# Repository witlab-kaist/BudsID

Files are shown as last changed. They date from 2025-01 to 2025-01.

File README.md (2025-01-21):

# BudsID
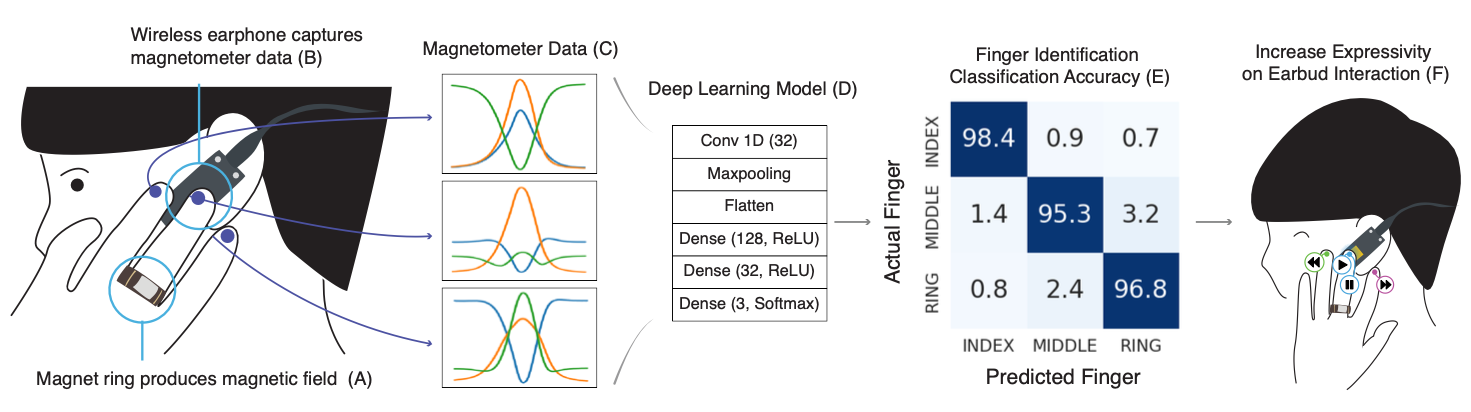
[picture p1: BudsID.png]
BudsID
    

BudsID: Mobile-Ready and Expressive Finger Identification Input for Earbuds.     
Jiwan Kim, Mingyu Han, and Ian Oakley    
CHI '25: Proceedings of the 2025 CHI conference on Human Factors in Computing systems.    
[DOI]() | [Video]()    

## About
This open-source provides software, hardware, and classifier for BudsID.

## Software
```
Software/    
├── Arduino_LSM9DS1.zip    
├── Arduino_TensorFlowLite.zip     
├── nanoBuds_v4/    
│   ├── model.h     
│   ├── nanoBuds_v4.ino     
│   ├── src/    
│   │   ├── CapacitiveSensor/    
├── nanoBudsBLE_v5/    
│   ├── index.html    
│   ├── nanoBudsBLE_v5.js    
│   └── libraries/    
└── readMe.txt    
```
- Arduino_LSM9DS1.zip: This archive contains external libraries required for achieving a higher magnetometer sampling rate.
- Arduino_TensorFlowLite.zip: Libraries to enable tinyML on microcontollers
- nanoBuds_v4/:
    - nanoBuds_v4.ino: This Arduino (.ino) file consists of the code responsible for BLE communication and TensorFlow Lite for Microcontrollers.
- model.h: trained model.
- CapacitiveSensor/: This directory contains an external library related to capacitive sensing.
- nanoBudsBLE_v5/:
    - index.html: This webpage provides a user interface for viewing magnetometer, accelerometer, gyroscope data, and capacitive touch inputs via a BLE connection.
- readMe.txt: This is the project's README file, providing additional details and instructions.
- Data preprocessing and classifier code will be shared with github repository with publication of this work.

## Hardware
#### Components:    
Parts - Sensor unit   
> https://store-usa.arduino.cc/products/arduino-nano-33-ble-sense   
> Resistors and 7mm x 7mm x 0.7 plated PCB (for electrode):   
> 	- https://playground.arduino.cc/Main/CapacitiveSensor/   

Parts - Battery unit   
> Voltage booster: https://www.adafruit.com/product/4654   
> Battery: 3.7 li-ion (36 x 17 x 6.5mm)   
> Charger: see included kicad project, based on https://www.adafruit.com/product/2124   

USB micro Cable: any with diameter ~4mm.   

#### Assembly Instructions:   
```
1. Create a sensor or battery module for left or right ear using an appopriate base and top part. 
(sensorBaseLeft.stl plus sensorTop.stl are for a left sensor earbud, powerBaseRight.stl plus powerTop.stl are for a right power earbud).   
2. The battery unit clicks shut.    
3. The sensor unit should be secured with M1 bolts (10mm) and nuts.    
4. Screw the appropriate earLoop (left or right) to the loopToBaseConnector with an M2 bolt (8-12mm) and nut. The nut is in the connector.    
5. Slide the connector onto the sensor or battery base (it will be very stiff).    
6. Push the outerEarStrut into the hole on the earLoop and fit a rubber earbud over it.    
```

## Classifier    
BudsID_classifier.ipynb file illustrate preprocessing and classifier design code.   

## Contact    
Jiwan Kim: [kjwan4435@gmail.com](mailto:kjwan4435@gmail.com)

## Reference

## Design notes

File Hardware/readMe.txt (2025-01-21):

Assembly Instructions:

All models are in the Models folder

Create a sensor or battery module for left or right ear using an appopriate base and top part. For example:
sensorBaseLeft.stl plus sensorTop.stl are for a left sensor earbud
powerBaseRight.stl plus powerTop.stl are for a right power earbud

The battery unit clicks shut. The sensor unit should be secured with M1 bolts (10mm) and nuts. 

Screw the appropriate earLoop (left or right) to the loopToBaseConnector with an M2 bolt (8-12mm) and nut. The nut is in the connector. 

Slide the connector onto the sensor or battery base (it will be very stiff). 

Push the outerEarStrut into the hole on the earLoop and fit a rubber earbud over it. 

Parts - Sensor unit
https://store-usa.arduino.cc/products/arduino-nano-33-ble-sense
Resistors and 7mm x 7mm x 0.7 plated PCB (for electrode):
	- https://playground.arduino.cc/Main/CapacitiveSensor/

Parts - Battery unit
Voltage booster: https://www.adafruit.com/product/4654
Battery: 3.7 li-ion (36 x 17 x 6.5mm)
Charger: see included kicad project, based on https://www.adafruit.com/product/2124
USB micro Cable: any with diameter ~4mm.

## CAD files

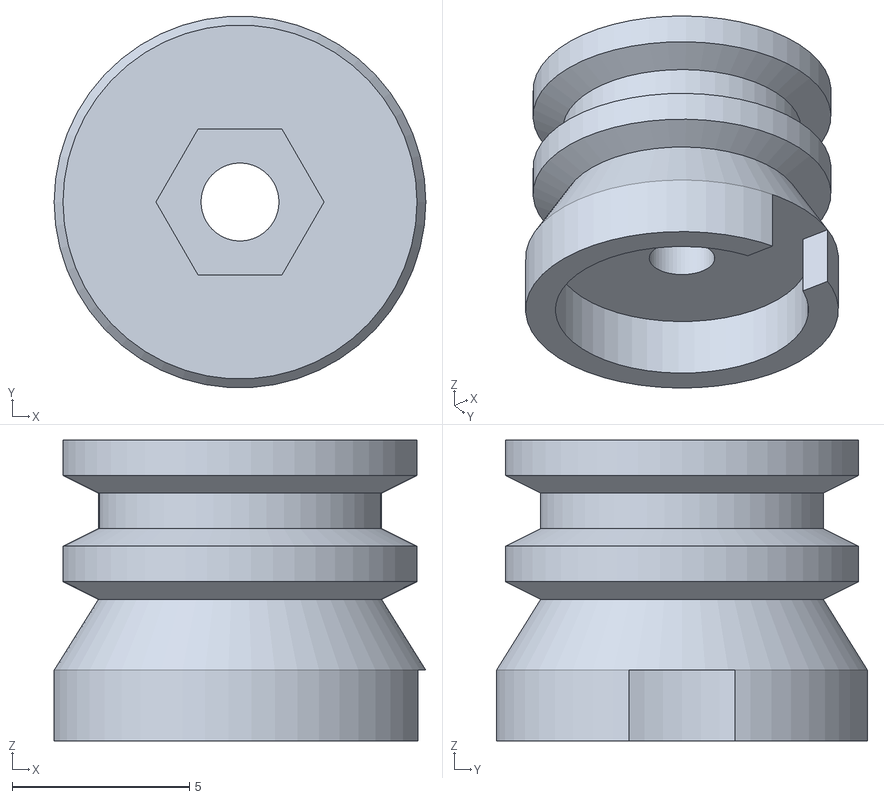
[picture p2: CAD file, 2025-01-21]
Hardware/Models/loopToBaseConnector.stl
10.5 x 10.5 x 8.50

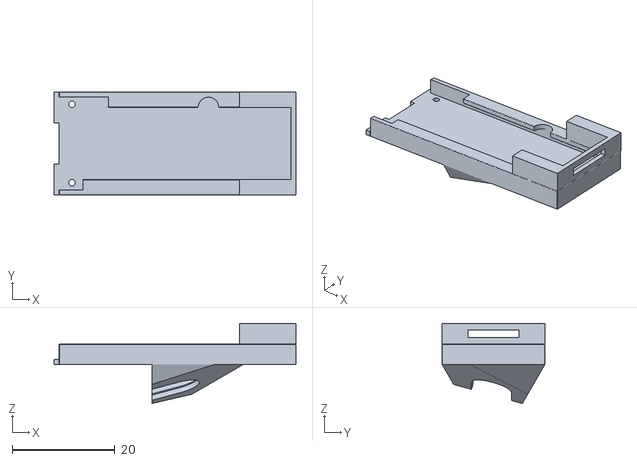
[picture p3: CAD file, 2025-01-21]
Hardware/Models/sensorBaseLeft.stl
47.0 x 20.0 x 15.5

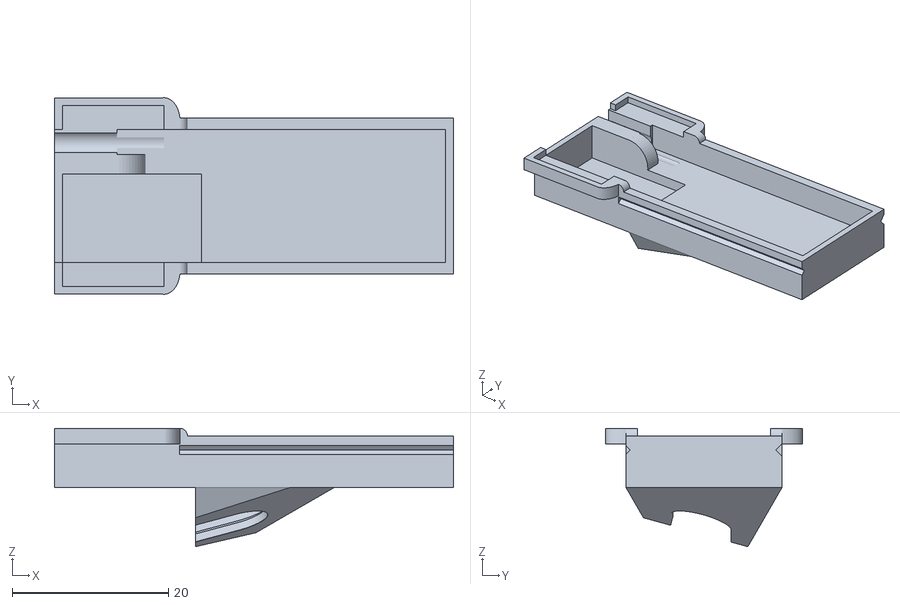
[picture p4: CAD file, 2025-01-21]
Hardware/Models/powerBaseLeft.stl
51.0 x 25.1 x 15.1

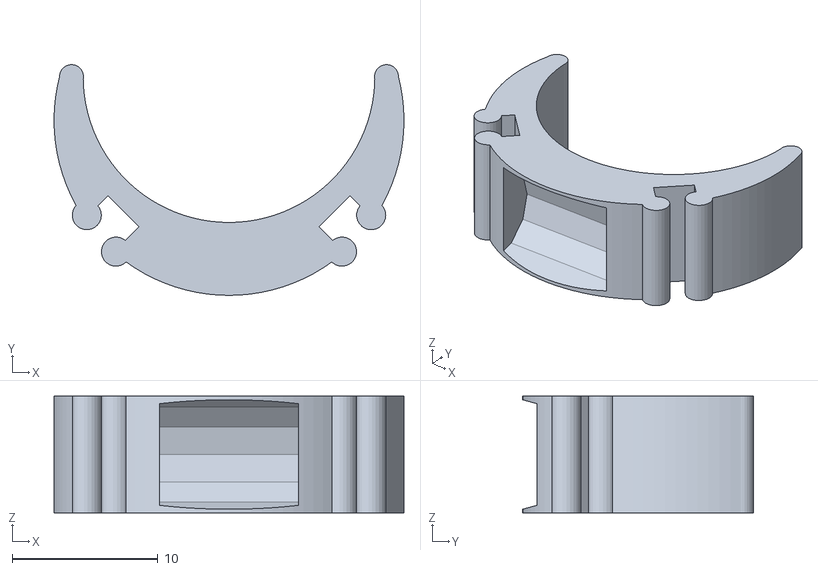
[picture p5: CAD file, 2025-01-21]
Hardware/Models/magnetRing.stl
24.0 x 15.8 x 8.00

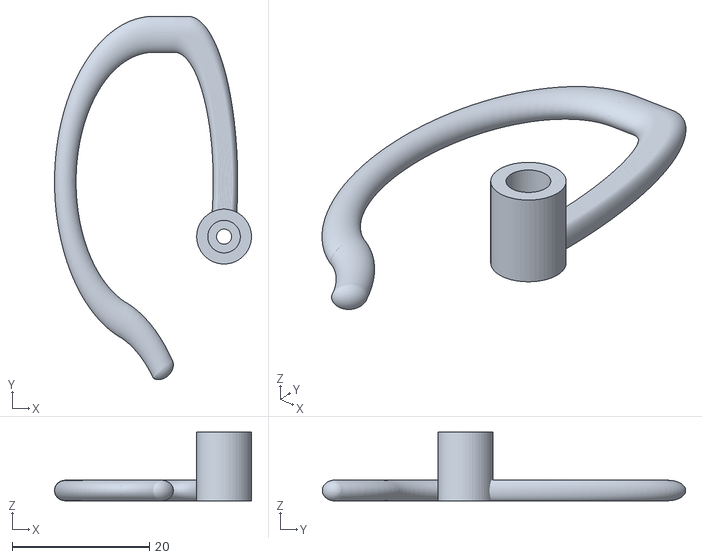
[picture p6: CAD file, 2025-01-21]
Hardware/Models/earLoopLeft.stl
28.7 x 53.0 x 10.0

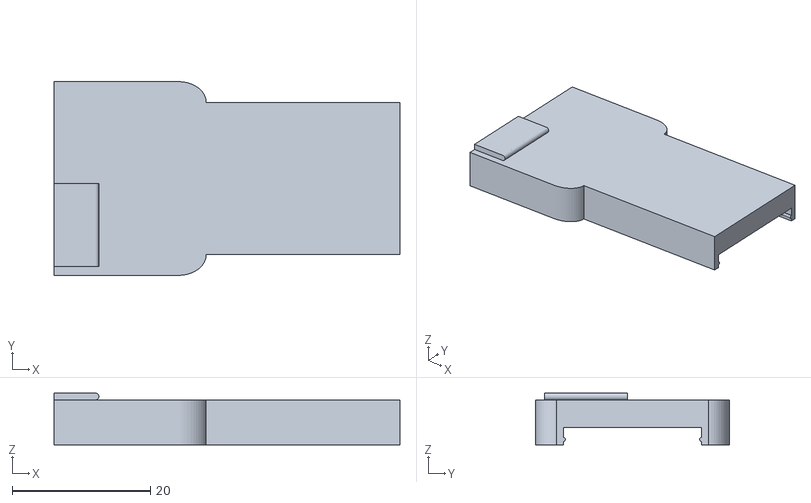
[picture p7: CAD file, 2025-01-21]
Hardware/Models/powerTop.stl
50.0 x 28.0 x 7.50

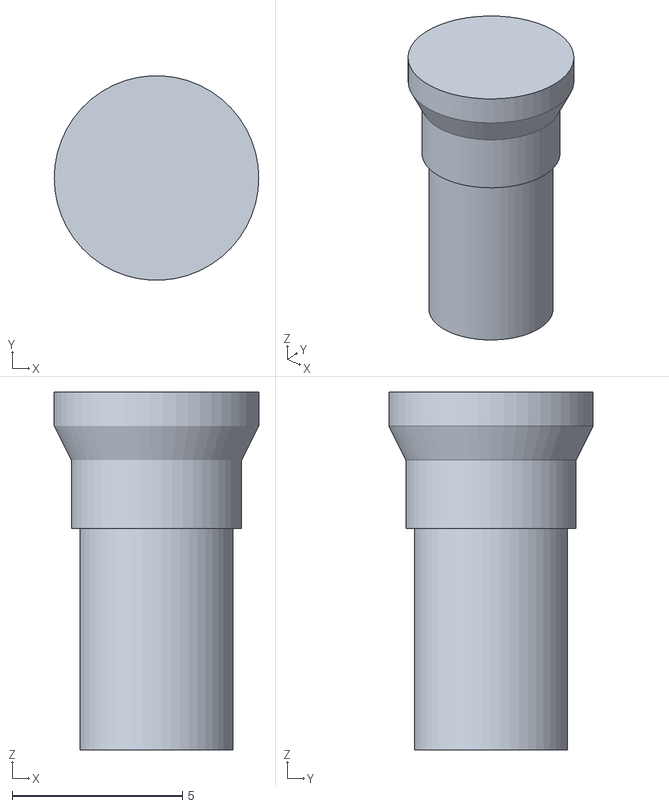
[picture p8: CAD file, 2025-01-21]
Hardware/Models/outerEarStrut.stl
6.00 x 5.99 x 10.5

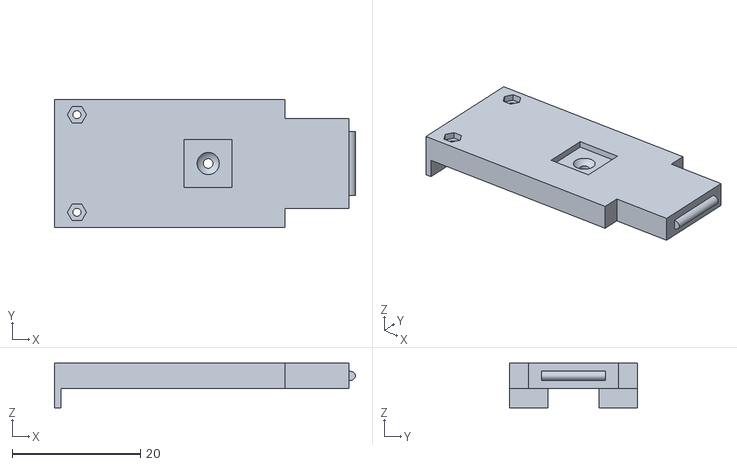
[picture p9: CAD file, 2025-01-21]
Hardware/Models/sensorTop.stl
47.0 x 20.0 x 7.00

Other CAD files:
Hardware/Models/earLoopRight.stl
Hardware/Models/sensorBaseRight.stl
Hardware/Models/powerBaseRight.stl

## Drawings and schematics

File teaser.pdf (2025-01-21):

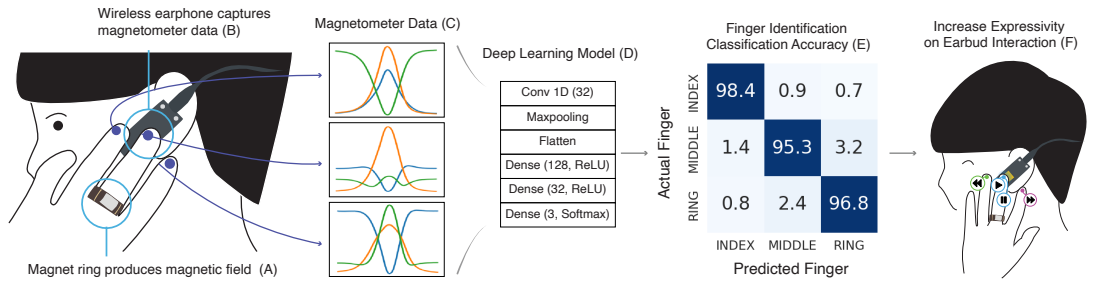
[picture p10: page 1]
Magnetometer Data (C); Conv 1D (32); Finger Identification Classification Accuracy (E); Actual Finger; Predicted Finger; Maxpooling Flatten Dense (128, ReLU) Dense (32, ReLU) Dense (3, Softmax)

Wireless earphone captures
magnetometer data (B)

Increase Expressivity
on Earbud Interaction (F)

Deep Learning Model (D)

Magnet ring produces magnetic field (A)

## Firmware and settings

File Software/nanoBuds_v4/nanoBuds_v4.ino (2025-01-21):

#include <ArduinoBLE.h>
// #include <Arduino_LSM9DS1.h>
#include <TensorFlowLite.h>
#include <tensorflow/lite/micro/all_ops_resolver.h>
#include <tensorflow/lite/micro/micro_error_reporter.h>
#include <tensorflow/lite/micro/micro_interpreter.h>
#include <tensorflow/lite/version.h>
#include <tensorflow/lite/schema/schema_generated.h>
#include <tensorflow/lite/micro/micro_mutable_op_resolver.h>
// #include <tensorflow/lite/micro/system_setup.h>

#include "src/acceleratedIMU/src/Arduino_LSM9DS1.h"
#include "src/CapacitiveSensor/CapacitiveSensor.h"
#include "model.h"

// we use sensor with 7mm by 7mm square electrode and 1kOhm and 1MOhm resistors. 

// *************************************************************************************
// IMPORTANT: comment out this line for the right bud; leave it defined for the left bud
#define USE_LEFT_BUD
// *************************************************************************************

#ifdef USE_LEFT_BUD
CapacitiveSensor   cs_3_12 = CapacitiveSensor(3,12);        // 10M resistor between pins 4 & 2, pin 2 is sensor pin, add a wire and or foil if desired
#else
CapacitiveSensor   cs_3_12 = CapacitiveSensor(12,3);        // 10M resistor between pins 4 & 2, pin 2 is sensor pin, add a wire and or foil if desired
#endif

#ifdef USE_SINGLE_CHARS
  #ifdef USE_LEFT_BUD  // prefix: 21B58C
  BLEService budsService("21B58C3D-D0E0-4E70-9CEA-45C8FFFF8CD7"); // Bluetooth® Low Energy LED Service
  
  BLEFloatCharacteristic accCharacteristic("21B58C42-D0E0-4E70-9CEA-45C8FFFF8CD7", BLERead | BLENotify);
  BLEFloatCharacteristic yAccCharacteristic("21B58C43-D0E0-4E70-9CEA-45C8FFFF8CD7", BLERead | BLENotify);
  BLEFloatCharacteristic zAccCharacteristic("21B58C44-D0E0-4E70-9CEA-45C8FFFF8CD7", BLERead | BLENotify);
  
  BLEFloatCharacteristic xGyrCharacteristic("21B58C45-D0E0-4E70-9CEA-45C8FFFF8CD7", BLERead | BLENotify);
  BLEFloatCharacteristic yGyrCharacteristic("21B58C46-D0E0-4E70-9CEA-45C8FFFF8CD7", BLERead | BLENotify);
  BLEFloatCharacteristic zGyrCharacteristic("21B58C47-D0E0-4E70-9CEA-45C8FFFF8CD7", BLERead | BLENotify);
  
  BLEFloatCharacteristic xMagCharacteristic("21B58C3E-D0E0-4E70-9CEA-45C8FFFF8CD7", BLERead | BLENotify);
  BLEFloatCharacteristic yMagCharacteristic("21B58C3F-D0E0-4E70-9CEA-45C8FFFF8CD7", BLERead | BLENotify);
  BLEFloatCharacteristic zMagCharacteristic("21B58C40-D0E0-4E70-9CEA-45C8FFFF8CD7", BLERead | BLENotify);
  
  BLEFloatCharacteristic capCharacteristic ("21B58C41-D0E0-4E70-9CEA-45C8FFFF8CD7", BLERead | BLENotify);
  
  BLEFloatCharacteristic timeCharacteristic("21B58C48-D0E0-4E70-9CEA-45C8FFFF8CD7", BLERead | BLENotify);
  #else                // prefix: 21B58D
  BLEService budsService("21B58D3D-D0E0-4E70-9CEA-45C8FFFF8CD7"); // Bluetooth® Low Energy LED Service
  
  BLEFloatCharacteristic xAccCharacteristic("21B58D42-D0E0-4E70-9CEA-45C8FFFF8CD7", BLERead | BLENotify);
  BLEFloatCharacteristic yAccCharacteristic("21B58D43-D0E0-4E70-9CEA-45C8FFFF8CD7", BLERead | BLENotify);
  BLEFloatCharacteristic zAccCharacteristic("21B58D44-D0E0-4E70-9CEA-45C8FFFF8CD7", BLERead | BLENotify);
  
  BLEFloatCharacteristic xGyrCharacteristic("21B58D45-D0E0-4E70-9CEA-45C8FFFF8CD7", BLERead | BLENotify);
  BLEFloatCharacteristic yGyrCharacteristic("21B58D46-D0E0-4E70-9CEA-45C8FFFF8CD7", BLERead | BLENotify);
  BLEFloatCharacteristic zGyrCharacteristic("21B58D47-D0E0-4E70-9CEA-45C8FFFF8CD7", BLERead | BLENotify);
  
  BLEDoubleCharacteristic xMagCharacteristic("21B58D3E-D0E0-4E70-9CEA-45C8FFFF8CD7", BLERead | BLENotify);
  BLEDoubleCharacteristic yMagCharacteristic("21B58D3F-D0E0-4E70-9CEA-45C8FFFF8CD7", BLERead | BLENotify);
  BLEDoubleCharacteristic zMagCharacteristic("21B58D40-D0E0-4E70-9CEA-45C8FFFF8CD7", BLERead | BLENotify);
  
  BLEFloatCharacteristic capCharacteristic ("21B58D41-D0E0-4E70-9CEA-45C8FFFF8CD7", BLERead | BLENotify);
  
  BLEFloatCharacteristic timeCharacteristic("21B58D48-D0E0-4E70-9CEA-45C8FFFF8CD7", BLERead | BLENotify);
  #endif
#else
  #ifdef USE_LEFT_BUD  // prefix: 21B58C
  BLEService budsService("21B58C3D-D0E0-4E70-9CEA-45C8FFFF8CD7"); // Bluetooth® Low Energy LED Service

  BLEDoubleCharacteristic accCharacteristic ("21B58C50-D0E0-4E70-9CEA-45C8FFFF8CD7", BLERead | BLENotify);
  BLEDoubleCharacteristic gyrCharacteristic ("21B58C51-D0E0-4E70-9CEA-45C8FFFF8CD7", BLERead | BLENotify);
  BLEDoubleCharacteristic magCharacteristic ("21B58C52-D0E0-4E70-9CEA-45C8FFFF8CD7", BLERead | BLENotify);
  BLEDoubleCharacteristic dataCharacteristic("21B58C53-D0E0-4E70-9CEA-45C8FFFF8CD7", BLERead | BLENotify);
  
  #else                // prefix: 21B58D
  BLEService budsService("21B58D3D-D0E0-4E70-9CEA-45C8FFFF8CD7"); // Bluetooth® Low Energy LED Service

  BLEDoubleCharacteristic accCharacteristic ("21B58D50-D0E0-4E70-9CEA-45C8FFFF8CD7", BLERead | BLENotify);
  BLEDoubleCharacteristic gyrCharacteristic ("21B58D51-D0E0-4E70-9CEA-45C8FFFF8CD7", BLERead | BLENotify);
  BLEDoubleCharacteristic magCharacteristic ("21B58D52-D0E0-4E70-9CEA-45C8FFFF8CD7", BLERead | BLENotify);
  BLEDoubleCharacteristic dataCharacteristic("21B58D53-D0E0-4E70-9CEA-45C8FFFF8CD7", BLERead | BLENotify);
  #endif
#endif

long updateMS = 1;//1000.0/80.0; // 12.5ms
long lastMS   = 0; 
long btPollMS = 0; 

constexpr int tensorArenaSize = 64 * 1024;
byte tensorArena[tensorArenaSize];

// global variables used for TensorFlow Lite (Micro)
tflite::ErrorReporter* error_reporter = nullptr;
tflite::AllOpsResolver tflOpsResolver;
const tflite::Model *tflModel = nullptr;
tflite::MicroInterpreter *tflInterpreter = nullptr;
TfLiteTensor* tflInputTensor = nullptr;
TfLiteTensor *tflOutputTensor = nullptr;

constexpr int magnet_height = 80;
constexpr int magnet_channels = 3;
constexpr int magnet_byte_count = magnet_height * magnet_channels;
float MagnetometerBuffer[magnet_byte_count];
constexpr int label_count = 3;
const char *labels[label_count] = { "index", "mid", "ring" };

int bufferIndex = 0; 
int capTotal = 0;
int capa = 0;
int BUFFER_SIZE = magnet_byte_count;

void budsConnectHandler(BLEDevice central) {
  // central connected event handler
  Serial.print("Connected event, central: ");
  Serial.println(central.address());
}

void budsDisconnectHandler(BLEDevice central) {
  // central disconnected event handler
  Serial.print("Disconnected event, central: ");
  Serial.println(central.address());
}

void shareData(String header, float x, float y, float z, float scale, BLEDoubleCharacteristic c, boolean showSerial) {
      // multiply for readability, convert to short (check for loss)
      short xS, yS, zS; 
      xS = (short)(x*scale); 
      yS = (short)(y*scale); 
      zS = (short)(z*scale); 
      
      uint64_t largeword  = ((((uint64_t) xS) << 48) & 0xFFFF000000000000);
               largeword |= ((((uint64_t) yS) << 32) & 0x0000FFFF00000000);
               largeword |= ((((uint64_t) zS) << 16) & 0x00000000FFFF0000);

      // share via BT
      if (BLE.connected()) {
        c.writeValue(largeword);
      }

      // share via serial
      if (Serial && showSerial) {
        Serial.print(header);
        Serial.print(x);
        Serial.print("\t");
        Serial.print(xS);
        Serial.print("\t");
        Serial.print(y);
        Serial.print("\t");
        Serial.print(yS);
        Serial.print("\t");
        Serial.print(z);
        Serial.print("\t");
        Serial.print(zS);
        Serial.println("\t");
      }
}

void normalization(){
  float max = 0;
  float min = 0;

  // Feature extraction(x,y,z)
  // 1. 2D(80*3), however TINY ML input should be like (x,y,z,x,y,z,x,y,z...) in 1D(240*1)
  // 2. magnetometer normalization
  for (int i = 0; i < 240; i = i + 3) {
    if( MagnetometerBuffer[i] < min ){
      min =  MagnetometerBuffer[i];
    } 
    if( MagnetometerBuffer[i] > max ){
      max =  MagnetometerBuffer[i];
    } 
  }
  for (int i = 0; i < 240; i = i + 3) {
    MagnetometerBuffer[i] = (MagnetometerBuffer[i] - min) / (max-min);
  }

  for (int i = 1; i < 240; i = i + 3) {
    if( MagnetometerBuffer[i] < min ){
      min =  MagnetometerBuffer[i];
    } 
    if( MagnetometerBuffer[i] > max ){
      max =  MagnetometerBuffer[i];
      } 
  }

  for (int i = 1; i < 240; i = i + 3) {
    MagnetometerBuffer[i] = (MagnetometerBuffer[i] - min) / (max-min);
  }

  for (int i = 2; i < 240; i = i + 3) {
    if( MagnetometerBuffer[i] < min ){
      min =  MagnetometerBuffer[i];
    } 
    if( MagnetometerBuffer[i] > max ){
      max =  MagnetometerBuffer[i];
      } 
  }
  for (int i = 2; i < 240; i = i + 3) {
    MagnetometerBuffer[i] = (MagnetometerBuffer[i] - min) / (max-min);
  }
}

void input(){
  // Model input
  for (int i = 0; i < 240; i++) {
    tflInputTensor->data.f[i] = MagnetometerBuffer[i];
  }
  TfLiteStatus invokeStatus = tflInterpreter->Invoke();
}

void output(){
  // Model output
  for (int i = 0; i < label_count; i++) {
    Serial.print(labels[i]);
    Serial.print(": ");
    float value = tflOutputTensor->data.f[i];
    Serial.println(value, 6);
  }

  capa = 0;
  bufferIndex = 0;
}

void setup() {
  static tflite::MicroErrorReporter micro_error_reporter;  
  error_reporter = &micro_error_reporter;
  tflModel = tflite::GetModel(model);
  tflInterpreter = new tflite::MicroInterpreter(tflModel, tflOpsResolver, tensorArena, tensorArenaSize, error_reporter);
  tflInterpreter->AllocateTensors();
  tflInputTensor = tflInterpreter->input(0);
  tflOutputTensor = tflInterpreter->output(0);

  Serial.begin(230400);

  // begin initialization
  if (!IMU.begin()) {
    Serial.println("Failed to initialize IMU!");
    while (1);
  }

  Serial.print("Sampling sensors (M/A/G) at: ");
  Serial.println(IMU.magneticFieldSampleRate());
  Serial.println(IMU.accelerationSampleRate());
  Serial.println(IMU.gyroscopeSampleRate());

  if (!BLE.begin()) {
    Serial.println("Starting Bluetooth® Low Energy module failed!");
    while (1);
  }

  // set advertised local name and service UUID:
#ifdef USE_LEFT_BUD
  BLE.setLocalName("NanoEarbuds");
  BLE.setDeviceName("NanoEarbuds");
#else
  BLE.setLocalName("NanoEarbudsRight");
  BLE.setDeviceName("NanoEarbudsRight");
#endif
  BLE.setAdvertisedService(budsService);


#ifdef USE_SINGLE_CHARS
  // add the characteristic to the service
  budsService.addCharacteristic(xMagCharacteristic);
  budsService.addCharacteristic(yMagCharacteristic);
  budsService.addCharacteristic(zMagCharacteristic);
  
  budsService.addCharacteristic(xAccCharacteristic);
  budsService.addCharacteristic(yAccCharacteristic);
  budsService.addCharacteristic(zAccCharacteristic);
  
  budsService.addCharacteristic(xGyrCharacteristic);
  budsService.addCharacteristic(yGyrCharacteristic);
  budsService.addCharacteristic(zGyrCharacteristic);
  
  budsService.addCharacteristic(capCharacteristic);

  budsService.addCharacteristic(timeCharacteristic);
#else
  budsService.addCharacteristic(accCharacteristic);
  budsService.addCharacteristic(gyrCharacteristic);
  budsService.addCharacteristic(magCharacteristic);
  budsService.addCharacteristic(dataCharacteristic);
#endif
  // add service
  BLE.addService(budsService);

  // assign event handlers for connected, disconnected to peripheral
  BLE.setEventHandler(BLEConnected, budsConnectHandler);
  BLE.setEventHandler(BLEDisconnected, budsDisconnectHandler);

  // start advertising
  BLE.advertise();
  Serial.println("Advertizing BLE EarBud Peripheral");
}

void loop() {
  // timer is approximate - we skip every now and then. 
  long nowMS = millis(); 
  capTotal = cs_3_12.capacitiveSensor(1);
  if (true) {
    BLE.poll();
    float x, y, z;
    shareData("Time/Cap:  ", (float)(nowMS%10000), (float)constrain(capTotal, 0, 2000), 0, 1, dataCharacteristic, false); 
    
    // read and share any new acc data
    if (IMU.accelerationAvailable()) {
      IMU.readAcceleration(x, y, z);
      shareData("Acc:  ", x, y, z, 1000, accCharacteristic, false); 
    }

    // read and share any new gyro data
    if (IMU.gyroscopeAvailable()) {
      IMU.readGyroscope(x, y, z);
      shareData("Gyr:  ", x, y, z, 100, gyrCharacteristic, false); 
    }

    // read any new mag data
    if (IMU.magneticFieldAvailable()) {
      IMU.readMagneticField(x, y, z);
      delay(100/42); //Our model input is 60hz. this delay code for 70hz -> 60hz.
      magML(x,y,z);
      shareData("Mag:  ", x, y, z, 100, magCharacteristic, false); 
    }
    lastMS = nowMS; 
  }
}

void magML(float mx, float my, float mz){
  if (bufferIndex == BUFFER_SIZE & capa == 0) {
    for (int i = 3; i < BUFFER_SIZE; i = i + 3) {
      MagnetometerBuffer[i - 3] = MagnetometerBuffer[i];
    }
    for (int i = 4; i < BUFFER_SIZE; i = i + 3) {
      MagnetometerBuffer[i - 3] = MagnetometerBuffer[i];
    }
    for (int i = 5; i < BUFFER_SIZE; i = i + 3) {
      MagnetometerBuffer[i - 3] = MagnetometerBuffer[i];
    }
    bufferIndex= bufferIndex-3;
  }

  if (bufferIndex < 240 & capa == 0) {
    MagnetometerBuffer[bufferIndex] = mx;
    bufferIndex++;
    MagnetometerBuffer[bufferIndex] = my;
    bufferIndex++;
    MagnetometerBuffer[bufferIndex] = mz;
    bufferIndex++;

  }

  if (capTotal >= 100 & capa == 0) {
    //get 40 samples when touched
    for (int i = 120; i < 240; i = i + 3) {
      MagnetometerBuffer[i - 120] = MagnetometerBuffer[i];
    }
    for (int i = 121; i < 240; i = i + 3) {
      MagnetometerBuffer[(i - 120)] = MagnetometerBuffer[i];
    }
    for (int i = 122; i < 240; i = i + 3) {
      MagnetometerBuffer[(i - 120)] = MagnetometerBuffer[i];
    }
    bufferIndex = 120;
    capa = 1;
  }

  if (capa == 1){
    MagnetometerBuffer[bufferIndex] = mx;
    bufferIndex++;
    MagnetometerBuffer[bufferIndex] = my;
    bufferIndex++;
    MagnetometerBuffer[bufferIndex] = mz;
    bufferIndex++;
    if (bufferIndex == BUFFER_SIZE) {
      normalization(); 
      input();
      output();
    }
  }
}
